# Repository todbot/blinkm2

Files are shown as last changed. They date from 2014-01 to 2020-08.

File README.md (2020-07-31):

blinkm_mk2
==========

## aka. BlinkM2, aka BlinkM as WS2812 / NeoPixel controller

### Key Features
* WS2812 / NeoPixel controller (of at least 16 pixels)
* On-board LEDs (maybe two or more)
* Small! (< 1 inch square)
* Stand-alone operation, as original BlinkM
* Inputs for controlling behavior
* Turn into tiny Arduino! (attiny85, attiny84)
* Default firmware is just Arduino sketch (uses awesome ATtinyCore)

### How is this different from blink(1) USB RGB LED?
* blink(1) is retail product, not programmable, tied to a computer, with more robust USB stack
* BlinkM2 / BlinkM Neo is a tiny Arduino, meant to work stand-alone

### Some future directions
* Connector for additional Neopixel LEDs (not just pads)
* USB-based? NO (Micronuclues bootloader, like Digispark), NOT I2C? (but could use A0)
* Serial as well as I2C?  Maybe with SoftSerial
* Should on-board LEDs be in-line or parallel to off-board?
* Can we switch them? (Need more pins then, no ATtiny85)
- Digispark based?
- events trigger patterns:
- CapSense using "ADCTouch" library  (can this work on ATtiny84/85 system?)
- put inbound resistor on inputs for protection?

### Notes:
- TinyTouchLib works on Digispark (ATtiny85 at 16.5MHZ), with light editing. See TinyTouchTest1 sketch

### Further Reading:
- See also PatternIdeas.md

-
-

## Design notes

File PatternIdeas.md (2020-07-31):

## Algorithmic Pattern ideas

* shift (shift_amount, led_start, led_cnt, time? ) (time==fader)
* color change (fade,ledn)
* hue change( hue, ledn)
* brighness change (brightness, ledn)
* set led ( ledn )

## advanced functions
* "alter color based on neighbors"
* "alter color based on position"
* "if neighbors are brighter than B, my brightness decrease by 10"
* "if neighbors hue is close to #FF, my hue increases by 5"

## INPUTS
* "input changes pattern"
* "input alters pattern"

## Examples

### example x: police flasher
- 0ms - set leds 1010101 to #ff0000
- 1ms set leds 01010101 to #0000ff
- 500ms set leds 010101 to #ff0000
- 501ms set leds 101010 to #0000ff

### example x: one-directional clyon
- 0ms - set leds 11111... to #000000
- 1ms - set leds 100000... to #ff000
- 100ms - shift left w/rotate
- go back 1

###  example x: bi-directional cylon
- 0ms - set leds 11111... to #000000
- 1ms - set leds 100000...
- 2ms - set ledcounter to 10
- 3ms - shift left
- 4ms - decrement ledcounter
- 100ms - go back 1 if ledcounter > 0

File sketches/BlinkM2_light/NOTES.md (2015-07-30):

Example JSON version of BlinkM2 light script
{
    "name" : "foo",
    "pattern":
    [
        { "cmd": "fadeRGB", "rgb": "#FFFFFF", "time": 1000, "ledn": 2 },
        { "cmd": "fadeRGB", "rgb": "#FF0000", "time": 1000, "ledn": 3 },
        { "cmd": "fadeRGB", "rgb": "#00FF00", "time": 1000, "ledn": 0 },
        { "cmd": "fadeRGB", "rgb": "#0000FF", "time": 1000, "ledn": 3 },
        { "cmd": "fadeRGB", "rgb": "#000000", "time": 1000, "ledn": 128 },
    ]
}

{
    { "cmd", "play", "id", 8, "start", 3, "len", 2, "reps", 2 },
    { "cmd", "jump", "pos", -3 },
    { "cmd", "roate", "amount", 1 },
    { "cmd", "fadeToHSV", "hsv", "#00FF80", ... },
    { "cmd", "randomRGB", "rgb", "#FF00FF", },

}
{
    "pattern0" :

    [ { "cmd": "fadeRGB", "rgb": "#00FF00", "time": 1000, "ledn": 0 },
      { "cmd": "fadeRGB", "rgb": "#0000FF", "time": 1000, "ledn": 3 },
      { "cmd": "fadeRGB", "rgb": "#000000", "time": 1000, "ledn": 129 } ],
    
    "pattern1" :
    
    [ { "cmd": "fadeRGB", "rgb": "#FF0000", "time":   0 },
      { "cmd": "fadeRGB", "rgb": "#0000FF", "time": 400 } ],

    "pattern8" :
    
    [ { "cmd": "fadeRGB", "rgb": "#003300", "time": 100 },
      { "cmd": "fadeRGB", "rgb": "#00ff00", "time": 100 },
      { "cmd": "fadeRGB", "rgb": "#666600", "time": 100 }, 
      { "cmd": "fadeRGB", "rgb": "#000000", "time":  50 },
      { "cmd": "fadeRGB", "rgb": "#FFFFFF", "time": 400 }, 
      { "cmd": "fadeRGB", "rgb": "#000000", "time":  50 } ],

    "patternplay" : 

    [ { "cmd": "fadeRGB", "rgb": "#000000", "time": 100 },
      { "cmd": "play", "id": 8, "start": 2, "len": 2, "reps": 4 },
      { "cmd": "play", "id": 8, "start": 4, "len": 2, "reps": 3 } ],

    "pattercylon" :

    [ { "cmd": "fadeRGB", "rgb": "#FF0000", "time": 500, "ledn": 1 },
      { "cmd": "rotate",  "amount": 1 },
      { "cmd": "jump",    "pos": -1 } ],

    "patternfire" :

    [ { "cmd": "randomRGB",  "rgb": "#FFCC00", "range": 40, "time":100, "ledn": 1 },
      { "cmd": "rotate",     "amount": 1 },
      { "cmd": "randomTime", "min": 50, "range":100 },
      { "cmd": "jump",       "pos": -3 } ],

    "patterninput1":
    
    [ { "cmd": "input",   "id": 1, "jumpOnLow": 3 },
      { "cmd": "fadeRGB", "rgb": "#ff00ff", "time": 100, "ledn": 0 },
      { "cmd": "jump",    "pos": -2 },
      { "cmd": "fadeRGB", "rgb": "#00ff00", "time": 100, "ledn": 0 } ],

}

```

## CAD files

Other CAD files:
schematic/blinkm_mk2a-render.skp
schematic/blinkm_mk2b2-render.skp
schematic/blinkm_mk2o_vs_blinkm.skp

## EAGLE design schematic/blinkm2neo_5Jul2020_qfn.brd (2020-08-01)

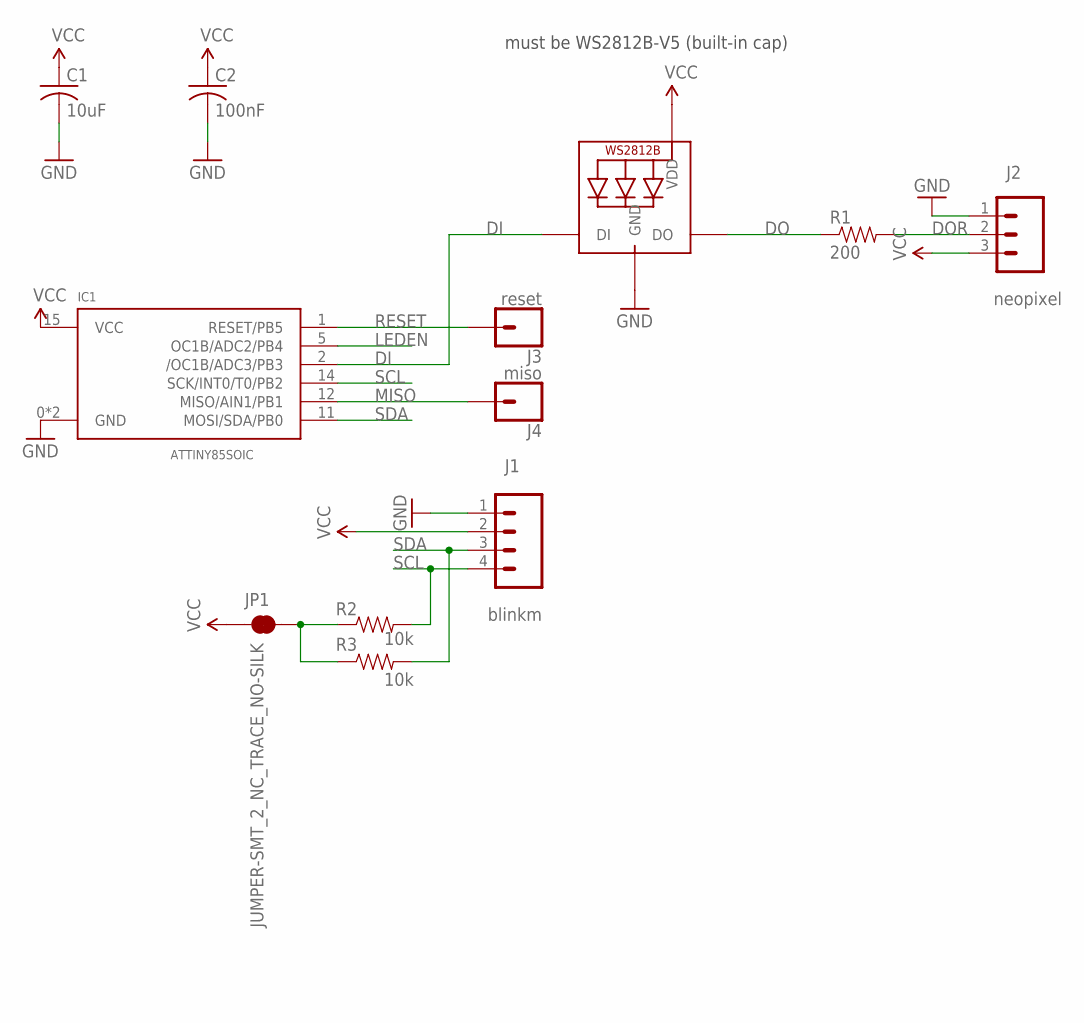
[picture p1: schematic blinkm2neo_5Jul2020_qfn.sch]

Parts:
C1: 10uF; C0402
C2: 100nF; C0402
IC1: ATTINY85SOIC; QFN20
J1: blinkm; 1X04
J2: neopixel; 1X03
J3: reset; 1X01_NO_SILK
J4: miso; 1X01_NO_SILK
JP1: JUMPER-SMT_2_NC_TRACE_NO-SILK; SMT-JUMPER_2_NC_TRACE_NO-SILK
LED1: WS2812B-V5; WS2812B
R1: 200; 0402
R2, R3: 10k; 0402

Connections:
DI: IC1.2 (/OC1B/ADC3/PB3), LED1.4-DIN (DI)
DO: LED1.2-DOUT (DO), R1.1
DOR: J2.2, R1.2
GND: C1.2, C2.2, IC1.0 (GND), IC1.8 (GND), J1.1, J2.1, LED1.3-GND (GND)
LEDEN: IC1.5 (OC1B/ADC2/PB4)
MISO: IC1.12 (MISO/AIN1/PB1), J4.1
unnamed: JP1.2, R2.1, R3.1
RESET: IC1.1 (RESET/PB5), J3.1
SCL: IC1.14 (SCK/INT0/T0/PB2), J1.4, R2.2
SDA: IC1.11 (MOSI/SDA/PB0), J1.3, R3.2
VCC: C1.1, C2.1, IC1.15 (VCC), J1.2, J2.3, JP1.1, LED1.1-VDD (VDD)

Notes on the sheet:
must be WS2812B-V5 (built-in cap)

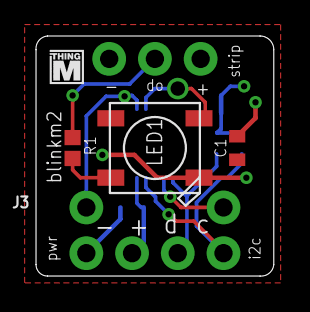
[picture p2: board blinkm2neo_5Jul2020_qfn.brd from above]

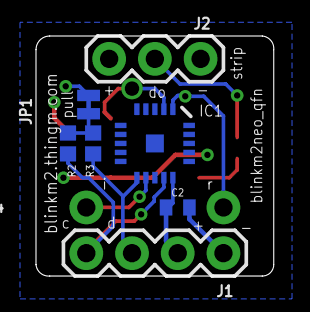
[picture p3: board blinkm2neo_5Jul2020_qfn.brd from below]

Board: 2 copper layers, 13.2 x 13.3 mm, 13 parts (8 on the bottom side), 10 nets.

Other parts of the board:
U$1: THINGM_LOGO_0.075IN

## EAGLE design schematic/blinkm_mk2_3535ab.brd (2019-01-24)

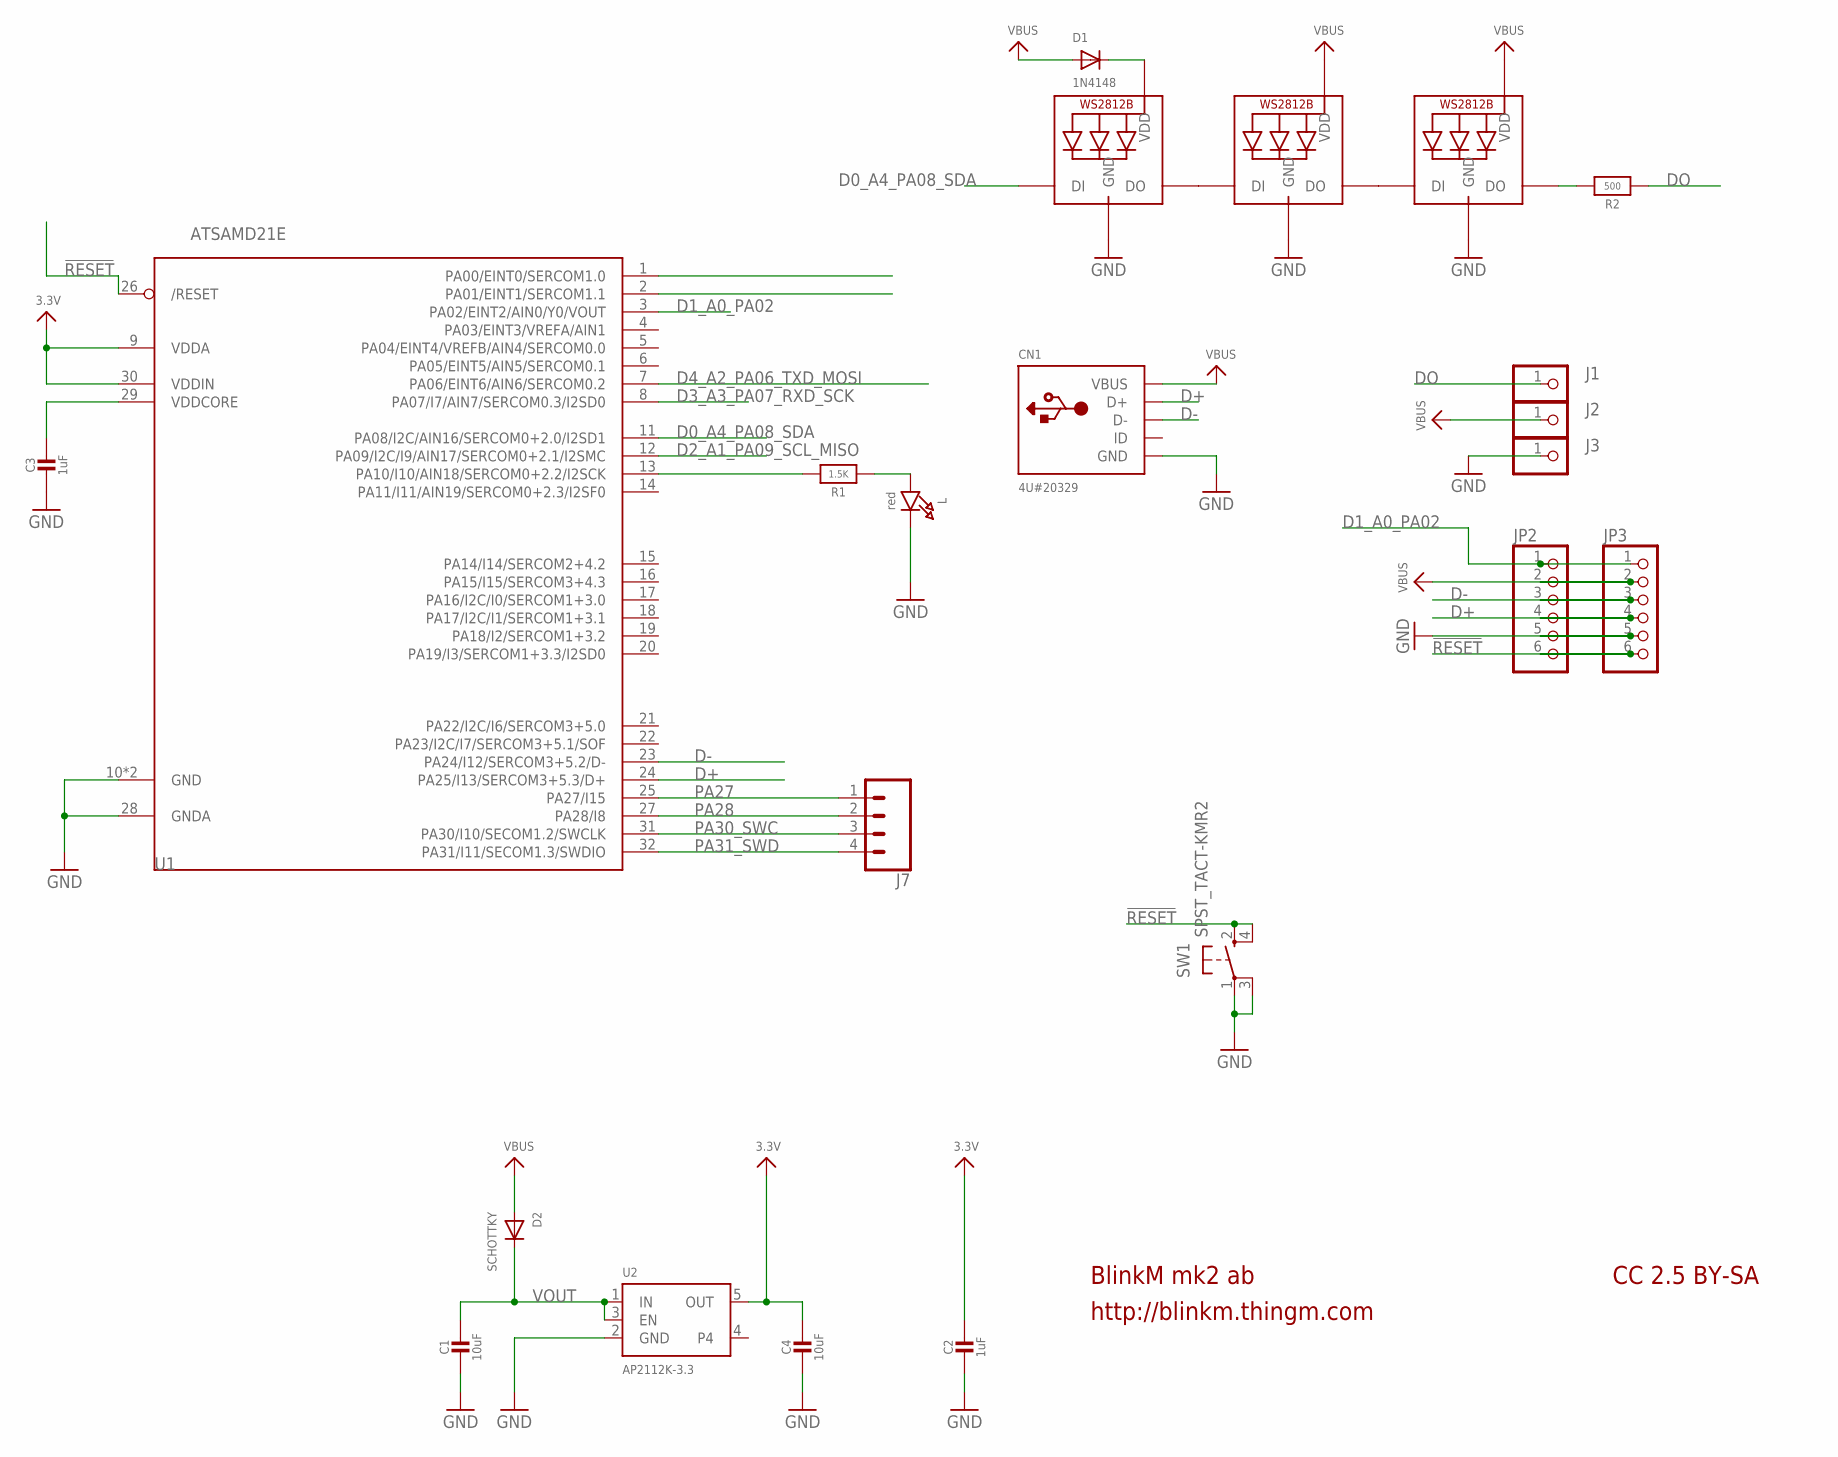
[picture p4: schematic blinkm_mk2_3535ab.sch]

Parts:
C1, C4: 10uF; _0402
C2, C3: 1uF; _0402
CN1: 4U#20329; 4UCONN_20329_V2
D1: 1N4148; SOD-523
D2: SCHOTTKY; SOD-523
J1, J2, J3: PINHD-1X1; 1X01
J7: CONN_041X04_NO_SILK; 1X04_NO_SILK
JP2, JP3: PINHD-1X6CLEAN; 1X06-CLEAN
L: red; CHIPLED_0603_NOOUTLINE
L1, L2, L3: WS2812B3535; LED3535
R1: 1.5K; _0402
R2: 500; _0402
SW1: SPST_TACT-KMR2; KMR2
U1: ATSAMD21E; QFN32_5MM
U2: AP2112K-3.3; SOT23-5

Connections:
3.3V: C2.1, C4.1, U1.9 (VDDA), U1.30 (VDDIN), U2.5 (OUT)
!RESET: JP2.6, JP3.6, SW1.2 (S), SW1.4 (S1), U1.26 (/RESET)
A3: U1.1 (PA00/EINT0/SERCOM1.0)
D0_A4_PA08_SDA: L1.1 (DI), U1.11 (PA08/I2C/AIN16/SERCOM0+2.0/I2SD1)
D1_A0_PA02: JP2.1, JP3.1, U1.3 (PA02/EINT2/AIN0/Y0/VOUT)
D2_A1_PA09_SCL_MISO: U1.12 (PA09/I2C/I9/AIN17/SERCOM0+2.1/I2SMC)
D3_A3_PA07_RXD_SCK: U1.8 (PA07/I7/AIN7/SERCOM0.3/I2SD0)
D4_A2_PA06_TXD_MOSI: U1.7 (PA06/EINT6/AIN6/SERCOM0.2)
D+: CN1.D+, JP2.4, JP3.4, U1.24 (PA25/I13/SERCOM3+5.3/D+)
D-: CN1.D-, JP2.3, JP3.3, U1.23 (PA24/I12/SERCOM3+5.2/D-)
DO: J1.1, R2.1
GND: C1.2, C2.2, C3.2, C4.2, CN1.BASE@1 (GND), CN1.BASE@2 (GND), CN1.GND, CN1.SPRT@1 (GND), CN1.SPRT@2 (GND), CN1.SPRT@3 (GND), CN1.SPRT@4 (GND), J3.1, JP2.5, JP3.5, L.C, L1.4 (GND), L2.4 (GND), L3.4 (GND), SW1.1, SW1.3 (P1), U1.10 (GND), U1.28 (GNDA), U1.33 (GND), U2.2 (GND)
unnamed: L.A, R1.1
unnamed: R1.2, U1.13 (PA10/I10/AIN18/SERCOM0+2.2/I2SCK)
unnamed: L1.3 (DO), L2.1 (DI)
unnamed: L3.3 (DO), R2.2
unnamed: L2.3 (DO), L3.1 (DI)
unnamed: D1.K (C), L1.2 (VDD)
PA27: J7.1, U1.25 (PA27/I15)
PA28: J7.2, U1.27 (PA28/I8)
PA30_SWC: J7.3, U1.31 (PA30/I10/SECOM1.2/SWCLK)
PA31_SWD: J7.4, U1.32 (PA31/I11/SECOM1.3/SWDIO)
VBUS: CN1.VBUS, D1.A, D2.A, J2.1, JP2.2, JP3.2, L2.2 (VDD), L3.2 (VDD)
VDDCORE: C3.1, U1.29 (VDDCORE)
VOUT: C1.1, D2.K (C), U2.1 (IN), U2.3 (EN)

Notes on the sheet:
BlinkM mk2 ab
http://blinkm.thingm.com
CC 2.5 BY-SA

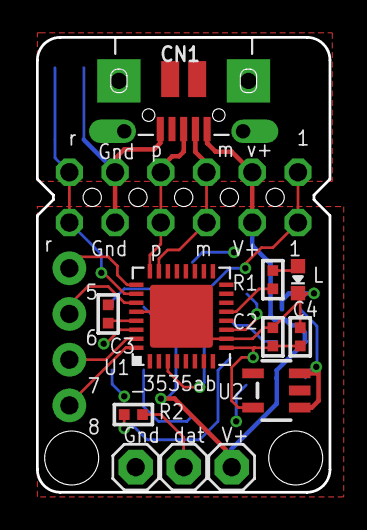
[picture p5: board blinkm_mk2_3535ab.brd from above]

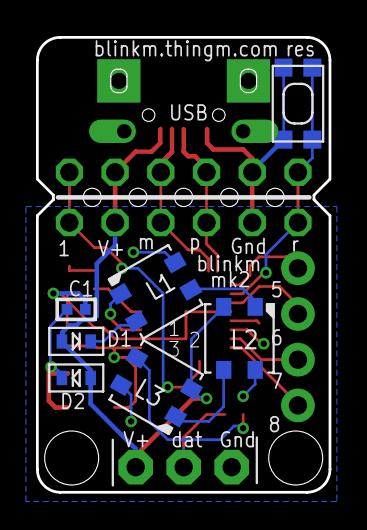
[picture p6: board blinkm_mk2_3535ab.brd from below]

Board: 2 copper layers, 16.3 x 25.3 mm, 22 parts (7 on the bottom side), 21 nets.

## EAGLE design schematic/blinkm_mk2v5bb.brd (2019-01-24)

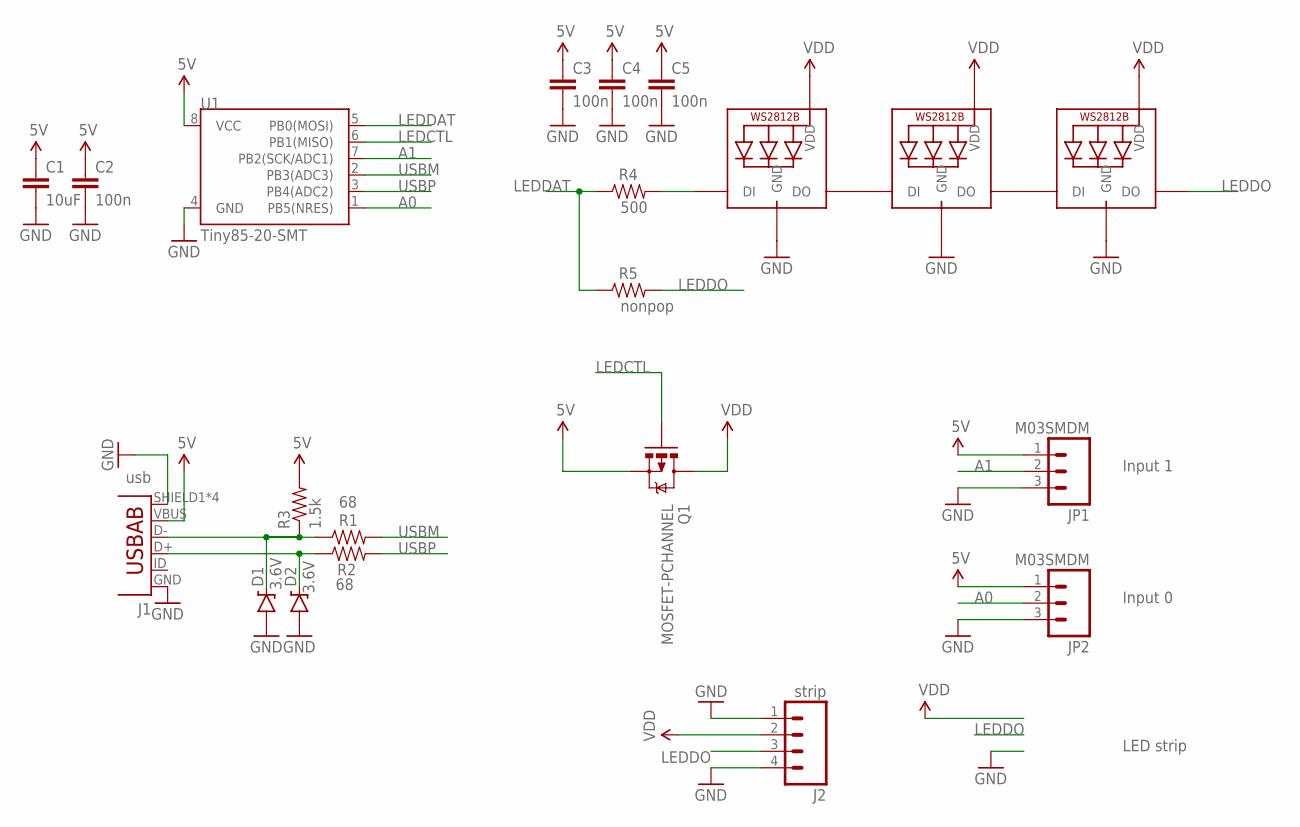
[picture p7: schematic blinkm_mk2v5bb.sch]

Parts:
C1: 10uF; 0603-CAP
C2, C3, C4, C5: 100n; 0603-CAP
D1, D2: 3.6V; SOD-323
J1: usb; USB-AB-MICRO-SMD
J2: strip; 1X04_NO_SILK_ALL_ROUND
JP1, JP2: M03SMDM; 1X03-SMD-MINIMAL
LED1, LED2, LED3: WS2812B3535; LED3535
Q1: MOSFET-PCHANNEL; SOT23-3
R1, R2: 68; 0603-RES
R3: 1.5k; 0603-RES
R4: 500; 0603-RES
R5: nonpop; 0603-RES
U1: Tiny85-20-SMT; SO08-EIAJ

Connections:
5V: C1.1, C2.1, C3.1, C4.1, C5.1, J1.VBUS, JP1.1, JP2.1, Q1.2 (S), R3.2, U1.8 (VCC)
A0: JP2.2, U1.1 (PB5(NRES))
A1: JP1.2, U1.7 (PB2(SCK/ADC1))
GND: C1.2, C2.2, C3.2, C4.2, C5.2, D1.A, D2.A, J1.GND, J1.SHIELD1 (SHIELD), J1.SHIELD2 (SHIELD), J1.SHIELD3 (SHIELD), J1.SHIELD4 (SHIELD), J2.1, J2.4, JP1.3, JP2.3, LED1.4 (GND), LED2.4 (GND), LED3.4 (GND), U1.4 (GND)
LEDCTL: Q1.1 (G), U1.6 (PB1(MISO))
LEDDAT: R4.1, R5.1, U1.5 (PB0(MOSI))
LEDDO: J2.3, LED3.3 (DO), R5.2
unnamed: LED1.3 (DO), LED2.1 (DI)
unnamed: LED2.3 (DO), LED3.1 (DI)
unnamed: D1.C, J1.D-, R1.1, R3.1
unnamed: D2.C, J1.D+, R2.1
unnamed: LED1.1 (DI), R4.2
USBM: R1.2, U1.2 (PB3(ADC3))
USBP: R2.2, U1.3 (PB4(ADC2))
VDD: J2.2, LED1.2 (VDD), LED2.2 (VDD), LED3.2 (VDD), Q1.3 (D)

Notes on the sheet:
Input 1
Input 0
LED strip

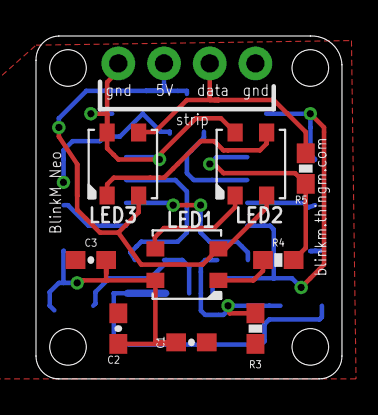
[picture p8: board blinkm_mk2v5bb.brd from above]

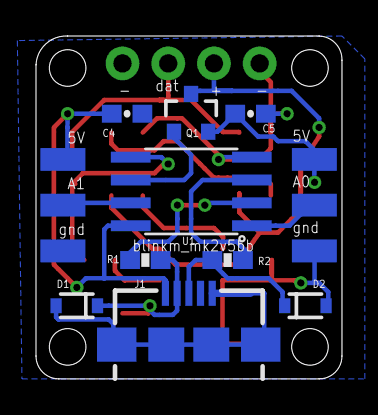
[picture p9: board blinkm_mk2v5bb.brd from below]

Board: 2 copper layers, 17.0 x 19.1 mm, 21 parts (11 on the bottom side), 15 nets.

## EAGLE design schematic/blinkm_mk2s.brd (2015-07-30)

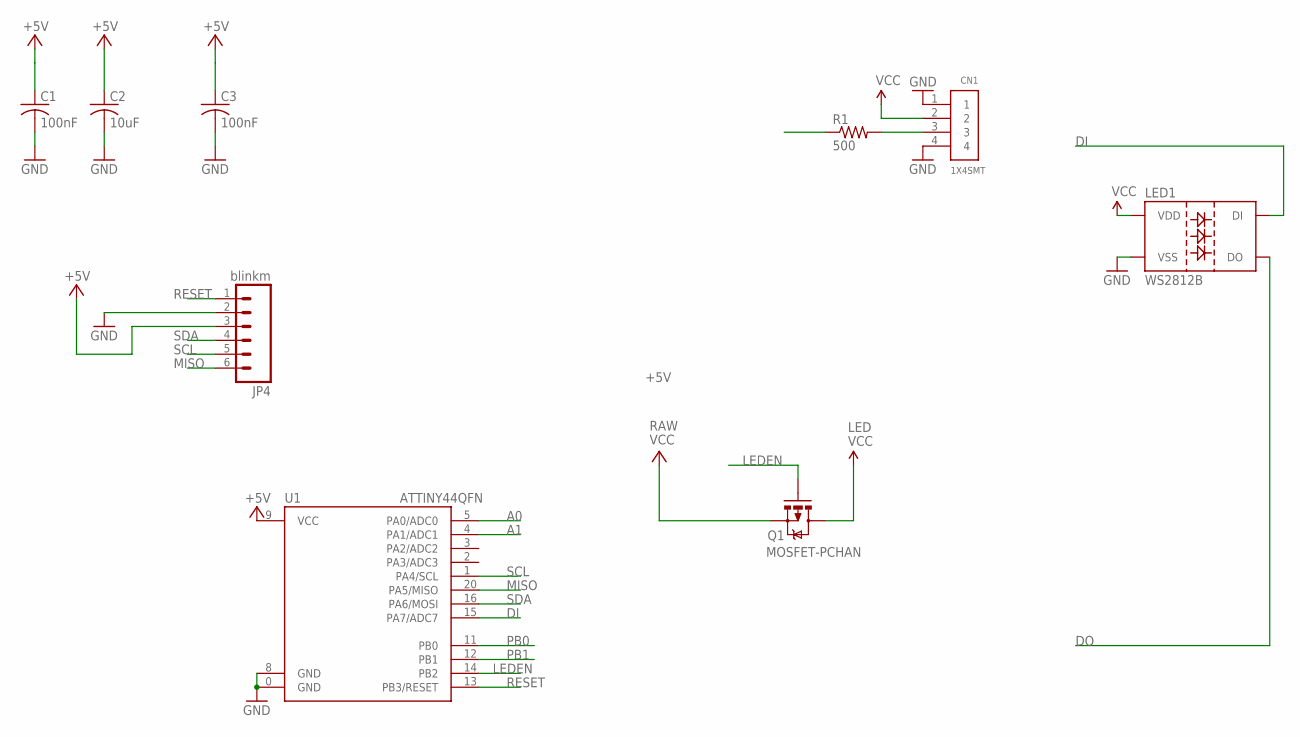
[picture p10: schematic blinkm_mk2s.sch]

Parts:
C1, C3: 100nF; C0603
C2: 10uF; C0603
CN1: 1X4SMT; 1X4-SMT
JP4: blinkm; 1X06_LOCK
LED1: WS2812B
Q1: MOSFET-PCHAN; SOT23-3
R1: 500; 0603-RES
U1: ATTINY44QFN; QFN20

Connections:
+5V: C1.1, C2.1, C3.1, JP4.3, Q1.2 (S), U1.9 (VCC)
A0: U1.5 (PA0/ADC0)
A1: U1.4 (PA1/ADC1)
DI: LED1.4 (DI), U1.15 (PA7/ADC7)
DO: LED1.2 (DO), R1.1
GND: C1.2, C2.2, C3.2, CN1.1, CN1.4, JP4.2, LED1.3 (VSS), U1.0 (GND), U1.8 (GND)
LEDEN: Q1.1 (G), U1.14 (PB2)
MISO: JP4.6, U1.20 (PA5/MISO)
unnamed: CN1.3, R1.2
PB0: U1.11 (PB0)
PB1: U1.12 (PB1)
RESET: JP4.1, U1.13 (PB3/RESET)
SCL: JP4.5, U1.1 (PA4/SCL)
SDA: JP4.4, U1.16 (PA6/MOSI)
VCC: CN1.2, LED1.1 (VDD), Q1.3 (D)

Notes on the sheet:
LED
VCC
RAW

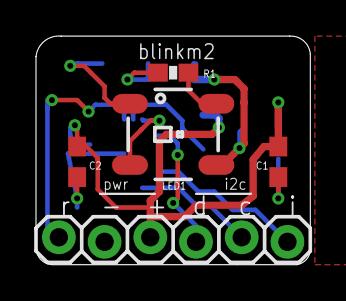
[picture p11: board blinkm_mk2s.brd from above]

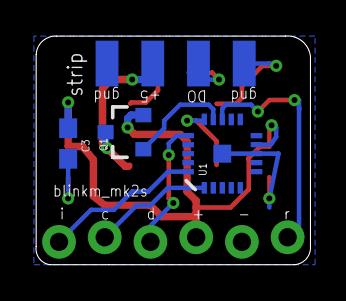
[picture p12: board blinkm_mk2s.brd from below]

Board: 2 copper layers, 15.2 x 12.7 mm, 9 parts (4 on the bottom side), 11 nets.

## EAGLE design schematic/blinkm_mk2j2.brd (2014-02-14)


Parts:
C1, C3, C4: 100nF; C0603
C2: 10uF; C0603
CN1: 1X4SMT; 1X4-SMT
JP1, JP2: M03SMDM; 1X03-SMD-MINIMAL
JP4: blinkm; 1X06_LOCK
LED1, LED2, LED3: WS2812B
Q1: MOSFET-PCHANNELIRLML2244; SOT23-3
SW1, SW2: SPST_TACT-KMR2; KMR2
U1: ATTINY44QFN; QFN20

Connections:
+5V: C1.1, C2.1, C3.1, C4.1, JP1.3, JP2.1, JP4.3, Q1.3 (D), U1.9 (VCC)
A0: JP2.2, SW1.3 (P1), U1.5 (PA0/ADC0)
A1: JP1.2, SW2.3 (P1), U1.4 (PA1/ADC1)
DI: CN1.3, LED1.4 (DI), U1.15 (PA7/ADC7)
DO: LED3.2 (DO)
DOI1: LED1.2 (DO), LED2.4 (DI)
DOI2: LED2.2 (DO), LED3.4 (DI)
GND: C1.2, C2.2, C3.2, C4.2, CN1.1, CN1.4, JP1.1, JP2.3, JP4.2, LED1.3 (VSS), LED2.3 (VSS), LED3.3 (VSS), SW1.4 (S1), SW2.4 (S1), U1.0 (GND), U1.8 (GND)
LEDEN: Q1.1 (G), U1.2 (PA3/ADC3)
MISO: JP4.6, U1.20 (PA5/MISO)
RESET: JP4.1, U1.13 (PB3/RESET)
SCL: JP4.5, U1.1 (PA4/SCL)
SDA: JP4.4, U1.16 (PA6/MOSI)
VCC: CN1.2, LED1.1 (VDD), LED2.1 (VDD), LED3.1 (VDD), Q1.2 (S)

Board: 2 copper layers, 15 parts (8 on the bottom side), 13 nets, no tracks yet.

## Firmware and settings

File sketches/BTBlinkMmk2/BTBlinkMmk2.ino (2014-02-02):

 /**
  * BTBlinkMmk2 --- 
  *
  * BlinkM algo tests on BlinkyTape
  *
  */


#include "FastLED.h"
#include "LEDFader.h"

#include <avr/pgmspace.h>    // for memcpy_P()
#include <avr/eeprom.h>  // FOR EEMEM
#include <avr/delay.h>
#include <stdio.h>
#include <stdarg.h>

// How many leds in your strip?
const int NUM_LEDS = 16;  // at most 16
//const int NUM_LEDS = 1;

//const int DATA_PIN = 0;   // maxm A0
//const int DATA_PIN = 7; // blinkmmk2
const int DATA_PIN = 13; // blinkytape

// Define the array of leds
CRGB leds[NUM_LEDS];
//rgb_t ctmp;
//uint16_t ttmp;   // temp time holder
//uint8_t ntmp;    // temp ledn holder

const  uint32_t led_update_millis = 10;  // tick msec
static uint32_t led_update_next = 0;
static uint32_t pattern_update_next = 0;

const uint8_t patt_max=16;

// the light sequence patterns
#include "patterns.h"

patt_info_t patt_info;

/*
uint8_t patt_id   = 0;
uint8_t playstart = 0; // start play position
uint8_t playend   = patt_max; // end play position
*/

uint8_t playcount = 0; // number of times to play loop, or 0=infinite
uint8_t playpos   = 0; // current play position
uint8_t playlen   = patt_max; // gets decremented

uint8_t playing = 0; // playing values: 0=off, 1=normal, 2==playing from powerup

patt_line_t pltmp;  // temp pattern holder

rgbfader_t faders[NUM_LEDS];
LEDFader ledfader(leds, faders, NUM_LEDS ); 

// printf_wrapper
void p(char *fmt, ... ) 
{
  char tmp[128]; // resulting string limited to 128 chars
  va_list args;
  va_start (args, fmt );
  vsnprintf(tmp, 128, fmt, args);
  va_end (args);
  Serial.print(tmp);
}

//
void setup() 
{ 
  Serial.begin(57600);
  delay(2000);
  Serial.println("BTBlinkMmk2!");
  delay(1500);
  Serial.println("here we go...");

  // load up EEPROM from flash, 
  // to deal with fact that Arduino uploader doesn't upload EEPROM
  // FIXME: need to check if we need to do this
  //ptmp.len = patt_max;
  //ptmp.lines = ee_patt_lines;

  for( uint8_t i=0; i<patt_max; i++ ) {
    memcpy_P( &pltmp, &(patt_lines_default[i]), sizeof(patt_line_t) ); 
    eeprom_write_block( &pltmp, &(ee_patt_lines[i]), sizeof(patt_line_t) );
  }

  FastLED.addLeds<WS2812B, DATA_PIN, GRB>(leds, NUM_LEDS);

#if 1
  for( int i=0; i< NUM_LEDS; i++ )  leds[i] = 0x000020;
  FastLED.show();
  delay(500);
  for( int i=0; i< NUM_LEDS; i++ )  leds[i] = 0x002000;
  FastLED.show();
  delay(500);
  for( int i=0; i< NUM_LEDS; i++ )  leds[i] = 0x000000;
  FastLED.show();
  delay(500);
#endif

  led_update_next = millis();
  pattern_update_next = millis();

  start_playing();
}

//
void loop() 
{ 
  updateLEDs();
  handleCmds();
}

void handleCmds() 
{
  

}

//
void displayLEDs()
{
  FastLED.show();
}

void handlePattLine(void)
{
    rgb_t    ctmp = pltmp.color;
    int      ttmp = pltmp.dmillis;
    uint16_t ntmp = pltmp.ledn;
    uint8_t  cmd  = pltmp.cmd;

    if( cmd==0 && ttmp == 0 ) {
        return;
    }

    switch(cmd) {
    case('n'): // go to rgb immediately
        ttmp = 1;  // and fall thru to 'c' case
    case('c'): // fade to rgb
        ledfader.setDest( ctmp, ttmp, ntmp );
        break;
    case('C'):  // random rgb
        ctmp.r = gamma(random(255));
        ctmp.g = gamma(random(255));
        ctmp.b = gamma(random(255));
        ledfader.setDest( ctmp, ttmp, ntmp );
        break;
    case('o'):
        playing = 0;
        break;
    case('p'):
        patt_info.id    = ntmp;
        patt_info.count = pltmp.args[1];
        patt_info.start = pltmp.args[2];
        patt_info.end   = pltmp.args[3];
        playing = 1;
        break;
    default:
        break;
    }
}

//
void updateLEDs(void)
{
    uint32_t now = millis();

    // update LED for fading every led_update_millis
    if( (long)(now - led_update_next) > 0 ) { 
      led_update_next += led_update_millis;
      ledfader.update();
      displayLEDs();
    }
    
    // playing light pattern
    if( playing ) {
      if( (long)(now - pattern_update_next) > 0  ) { // time to get next line
        
        if( patt_info.id == 0 ) { // eeprom
          eeprom_read_block(&pltmp,&ee_patt_lines[playpos],sizeof(patt_line_t));
        } 
        else {                  // flash
          patt_line_t* pp;
          memcpy_P(&pp, &patterns[ patt_info.id ], sizeof(patt_line_t*));
          memcpy_P(&pltmp, &pp[playpos],sizeof(patt_line_t));
        }

        pattern_update_next += pltmp.dmillis*10;

        handlePattLine();
    
        playpos++;
        if( playpos > patt_info.end ) {
          playpos = patt_info.start;
          patt_info.count--;
          if( patt_info.count == 0 ) {
            playing = 0; // done!
          } else if( patt_info.count==255 ) {
            patt_info.count = 0; // infinite playing
          }
        }
        
        p("patt:%d cnt:%d start:%d stop:%d pos:%d ttmp:%d\n", 
          patt_info.id, patt_info.count, patt_info.start, patt_info.end, 
          playpos, pltmp.dmillis*10);
        
      }

    } // playing
    else {
      p("stopped");
    }

}

void start_playing(void)
{

  if( patt_info.id == 0 ) {   // eeprom
  } 
  else { 
  }

  patt_info.id    = 1;

  patt_info.start = 0;
  patt_info.end   = 4;
  //patt_info.start = 0;
  //patt_info.end = patt_max;
  patt_info.count = 0;
  // if( patt_info.id == 0 ) { 
  //  playpos = eeprom_read_byte( 

  playpos = patt_info.start;

  playing = 1;
}

uint8_t GammaE[] = { 
0, 0, 0, 0, 0, 0, 0, 0, 0, 0, 0, 0, 0, 0, 0, 0,
0, 0, 0, 0, 0, 0, 1, 1, 1, 1, 1, 1, 1, 2, 2, 2,
2, 2, 2, 3, 3, 3, 3, 3, 4, 4, 4, 4, 5, 5, 5, 5,
6, 6, 6, 7, 7, 7, 8, 8, 8, 9, 9, 9, 10, 10, 11, 11,
11, 12, 12, 13, 13, 13, 14, 14, 15, 15, 16, 16, 17, 17, 18, 18,
19, 19, 20, 21, 21, 22, 22, 23, 23, 24, 25, 25, 26, 27, 27, 28,
29, 29, 30, 31, 31, 32, 33, 34, 34, 35, 36, 37, 37, 38, 39, 40,
40, 41, 42, 43, 44, 45, 46, 46, 47, 48, 49, 50, 51, 52, 53, 54,
55, 56, 57, 58, 59, 60, 61, 62, 63, 64, 65, 66, 67, 68, 69, 70,
71, 72, 73, 74, 76, 77, 78, 79, 80, 81, 83, 84, 85, 86, 88, 89,
90, 91, 93, 94, 95, 96, 98, 99,100,102,103,104,106,107,109,110,
111,113,114,116,117,119,120,121,123,124,126,128,129,131,132,134,
135,137,138,140,142,143,145,146,148,150,151,153,155,157,158,160,
162,163,165,167,169,170,172,174,176,178,179,181,183,185,187,189,
191,193,194,196,198,200,202,204,206,208,210,212,214,216,218,220,
222,224,227,229,231,233,235,237,239,241,244,246,248,250,252,255};
//
static uint8_t gamma( uint8_t n ) 
{
    return GammaE[n];
}

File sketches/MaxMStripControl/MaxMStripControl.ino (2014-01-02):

 /**
  * MaxMStripContorl -- 
  *
  * Some code take from TinyWireM/examples
  *
  * More on TinyWireS usage - see TinyWireS.h
  */

#include "TinyWireS.h"                  // wrapper class for I2C slave routines

#include "light_ws2812.h"


// BlinkM MaxM pins (see below for where this came from)
const int redPin = 8;   // PB2 OC0A
const int grnPin = 7;   // PA7 OC0B
const int bluPin = 5;   // PA5 OC1B
const int sdaPin = 6;   // PA6 
const int sclPin = 9;   // PA4
const int in0Pin = A0;  // PA0
const int in1Pin = A1;  // PA1
const int in2Pin = A2;  // PA2
const int in3Pin = A3;  // PA3

// From: blinkm/variants/tiny14/pins_arduino.h  
// (originally from: http://hlt.media.mit.edu/?p=1695 )
// ATMEL ATTINY84 / ARDUINO
//
//                           +-\/-+
//                     VCC  1|    |14  GND
//             (D 10)  PB0  2|    |13  AREF (D  0)
//             (D  9)  PB1  3|    |12  PA1  (D  1) 
//                     PB3  4|    |11  PA2  (D  2) 
//  PWM  INT0  (D  8)  PB2  5|    |10  PA3  (D  3) 
//  PWM        (D  7)  PA7  6|    |9   PA4  (D  4) 
//  PWM        (D  6)  PA6  7|    |8   PA5  (D  5)        PWM
//                           +----+

const int I2C_SLAVE_ADDR  = 0x09;     // default BlinkM addr

const int NUM_LEDS = 8;

typedef struct CRGB_ { uint8_t g; uint8_t r; uint8_t b; } CRGB;
CRGB leds[1]; //NUM_LEDS];


void setup()
{
  TinyWireS.begin(I2C_SLAVE_ADDR); 
  
  leds[0].r=32; leds[0].g=32; leds[0].b=32;

  ws2812_sendarray( (uint8_t*)leds, 3 );
  delay(500);
  
  pinMode( redPin, OUTPUT);   
  pinMode( grnPin, OUTPUT);  
  pinMode( bluPin, OUTPUT);  
  blink( redPin,1);
  blink( grnPin,1);
  blink( bluPin,1);

}

void loop()
{
  byte cmd;
  byte r,g,b;

  if( TinyWireS.available() ) { 

    cmd = TinyWireS.receive();    // first byte is command
    if( cmd == 'c' ) { 
      r = TinyWireS.receive();
      g = TinyWireS.receive();
      b = TinyWireS.receive();
      analogWrite( redPin, r );
      analogWrite( grnPin, g );
      analogWrite( bluPin, b );

    }
    // else if( cmd == 'h' ) { 
    //}
    else {
    }
  }
}


//
void blink(byte pin, byte times)
{ 
  for (byte i=0; i< times; i++){
    digitalWrite(pin,HIGH);
    delay (200);
    digitalWrite(pin,LOW);
    delay (100);
  }
}

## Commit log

2013-06-05 added some files
    [blinkm_mk2a-render.skp, blinkm_mk2a.brd, blinkm_mk2a.sch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]
2014-01-02 added blinkm_mk2c board idea
    [blinkm_mk2c.brd, blinkm_mk2c.sch]
2014-01-02 updated blinkm_mk2c board layout, fully routed
    [blinkm_mk2c.brd, blinkm_mk2c.sch]
2014-01-30 using new ledfader
2014-02-01 more better
    [blinkm_mk2j.brd, blinkm_mk2j.sch]
2014-02-14 more pcb layout ideas, more firmware
    [blinkm_mk2j1.brd, blinkm_mk2j1.sch, blinkm_mk2j2.brd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]
2015-06-08 had to move led_fader functions back to header file because of Arduino compile limitations (cannot use Serial.print() in other C file)
2015-06-11 first light on led pattern chooser
2015-06-12 added new ledn patterns
2015-06-18 added mk2r schem
    [blinkm_mk2r.brd, blinkm_mk2r.sch]
2015-06-22 woot, hopefully figured out smaller algo for fading
    [blinkm_mk2r.brd, blinkm_mk2r.sch]
2015-07-14 added single-led blinkm2 idea
    [blinkm_mk2s.brd, blinkm_mk2s.sch]
2015-07-15 blinkm2_light added patterns
    [blinkm_mk2s.brd]
2015-07-21 blinkm2_light pattern led rotation thinking coming together
2015-07-26 added misc other bits
    [blinkm_mk2o_vs_blinkm.skp]
2015-07-30 update before sketching15
    [blinkm_mk2s.brd, blinkm_mk2s.sch]
2016-07-18 added digispark-inspired usb-based blinkm neo idea
    [blinkm_mk2v5.brd, blinkm_mk2v5.sch]
2016-07-21 another usb-based idea
    [blinkm_mk2v5a.brd, blinkm_mk2v5a.sch]
2016-07-21 thoughts on touch-sensors
2019-01-24 added _3535aa,ab ideas
    [blinkm_mk2_3535aa.brd, blinkm_mk2_3535aa.sch, blinkm_mk2_3535ab.brd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]
2020-07-08 BlinkM2_Jul2020 reading scripts from flash correctly
    [BlinkM2_Jul2020.ino]
2020-07-31 updated ATtiny version to use standard Wire I2C events
2020-07-31 some potential BlinkM2 designs
    [blinkm2neo_5Jul2020_isp.brd, blinkm2neo_5Jul2020_isp.sch, blinkm2neo_5Jul2020_qfn.brd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]
2020-08-01 added pullup resistors
    [blinkm2neo_5Jul2020_qfn.brd, blinkm2neo_5Jul2020_qfn.sch]
2020-08-04 eeprom reset and general eeprom read/write mostly worknig
    [BlinkM2_Aug2020.ino, blinkm_config.h]
2020-08-04 rework eeprom handling to struct
    [BlinkM2_Aug2020.ino]

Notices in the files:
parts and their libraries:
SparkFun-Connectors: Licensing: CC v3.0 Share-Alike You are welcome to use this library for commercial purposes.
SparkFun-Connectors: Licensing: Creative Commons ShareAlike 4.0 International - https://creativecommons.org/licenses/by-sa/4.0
